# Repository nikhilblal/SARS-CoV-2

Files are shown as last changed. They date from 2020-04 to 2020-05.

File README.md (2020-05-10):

# SARS-CoV-2
 Repo for all pandemic related design work

 ## History

 Originally forked from the [Scale Workspace](https://www.scaleworkspace.com/) repo for face shield design around V2.1.
Files have been reuploaded here for clarity as there were revisions that did not make sense in the original pull request.

 ## Face Shield Design

The intention of this shield is for every component to be autoclavable and reusable. The typical die cut PC shields, although by material definition can withstand autoclave temperatures, are susceptible to damage during assembly, wear, and disassembly. By reducing the number of folds in the fragile clear sheet, the design is not as prone to tearing during these steps. Testing thinner than 0.020" thickness PC in an autoclave resulted in deformtion from the first cycle pointing to long term cyclical failure.

### Original Designs:
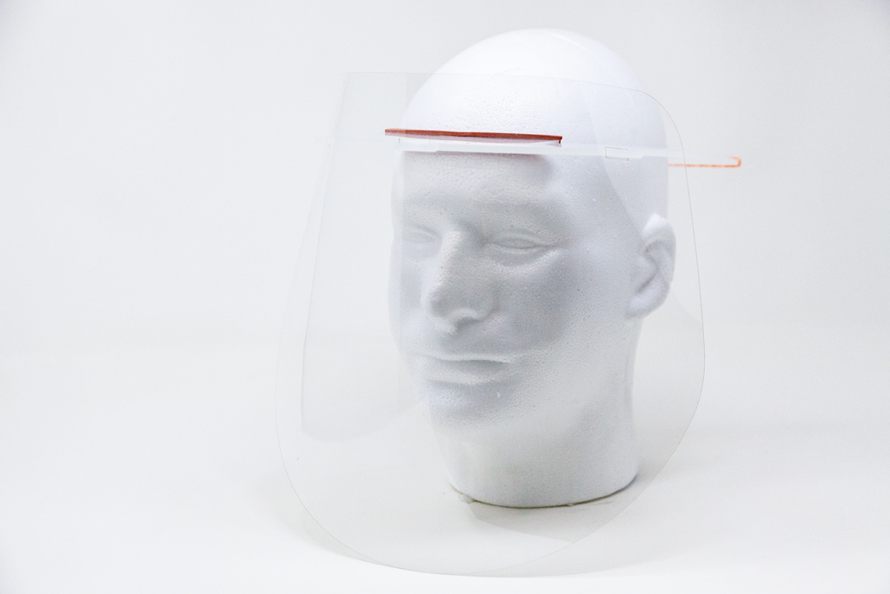
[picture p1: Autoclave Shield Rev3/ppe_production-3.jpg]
Autoclave Reusable Shield


### Materials

-Polypropylene (PP) Visor (suggest natural or Black)
-Polycarbonate (PC) Shield
-VMQ (silicone) Edging
-037 VMQ (silicone) O-ring, alt: hair tie, synthetic rubber band

Originally designed to be laser cut on a 90W CO2 Laser Cutter from [Black Cat Labs](https://www.blackcatlabs.xyz/), the Polypropylene consistently left large melt pools that were considered unacceptable by the end user. The rev2 designed has been optimized and nested for a CNC router using a 1/8" O Flute End Mill.

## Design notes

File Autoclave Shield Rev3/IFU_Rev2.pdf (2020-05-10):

Rev. #2 | Page 1

# Artisan’s Asylum Reusable Face Shield -Instructions for Use

These instructions for use correspond to Revision 2 of the Artisan’s Asylum Reusable Face Shield.

These Instructions for Use must be communicated to the End User of the Device

## Appropriate Use Criteria

This supplementary face shield was created as an emergency action in effort to provide protection as a backup Personal Protective Equipment (PPE) option if the traditional PPE devices have become unavailable. This device has not gone through the same regulatory approval process as traditional PPE, but has gone through a special verification process expedited strictly for the response to the COVID-19 pandemic.

This device is intended to be use only for the duration of the public health emergency related to COVID-19 declared by the Department of Health and Human Services (HHS), including any renewals made by the HHS Secretary in accordance with section 319(a)(2) of the Public Health Service Act (PHS Act).The decision to implement this device should be made with careful consideration and under the consultation of the corresponding institution’s occupational health and infection control departments.

A laser cut or 3D printed shield frame that can adapt to a variety of shield designs. The device is a face shield that can be fully autoclaved. Device was designed to follow ANSI standards Z87.1 and autoclave best practices.

The designer of this device does not warrant or guarantee efficacy, use at your own discretion.

The information included in this document provides device description and feature overview, recommended assembly steps, and cleaning instructions for reuse.

## Device Overview

A laser cut or 3D printed shield frame that can adapt to a variety of shield designs. Originally based off of the Scale Workspace reusable face shield, but optimized for mass production due to near tesselation of the print. Nesting the frames enables significant cycle time improvements. Currently produced in Somerville, MA (near Boston, MA) at Artisan's Asylum and provided to local health groups for testing. The original design that this design is based on, has been produced in New Orleans and provided to Ochsner in excess of 1350 QTY shipped and heavily tested.

Features:

- Top section covered to prevent droplets from above the forehead
- Sub 1 minute laser cut times out of 1/8" Polypropylene on a 100W laser
- Space for safety goggles, and a respirator
- Access for a stethoscope
- All materials are industry standard for autoclave sterilization (and UV safe, bleach safe, etc..)

The FDA has authorized production of protective face shields outside of the normal clearance pathway during the Covid-19 pandemic, based on Part 5, section D of the “Enforcement Policy for Face Masks and Respirators During the Coronavirus Disease (COVID-19) Public Health Emergency Guidance for Industry and Food and Drug Administration Staff.

This face shield has undergone review in a clinical setting and is recommended when fabricated as instructed.

Device to be disinfected per CDC guidelines, ideally this device is sterilized with steam treatment. Dispose of rubber bands between uses, the silicone comfort strip, polypropylene frame and polycarbonate visor may all be sterilized in typical medical autoclave. The author and designer of this device prefers using a dishwasher as that is the most convenient.

See Appendix A for recommended disinfecting solutions and sterilization methods for this device.

See Appendix B for guidelines on material selection.

Components to be disposed of after every use or immediately after potential contamination by bodily fluids
- Elastic band

Components to be disinfected and reused:
- Frame
- Visor
- Comfort strip

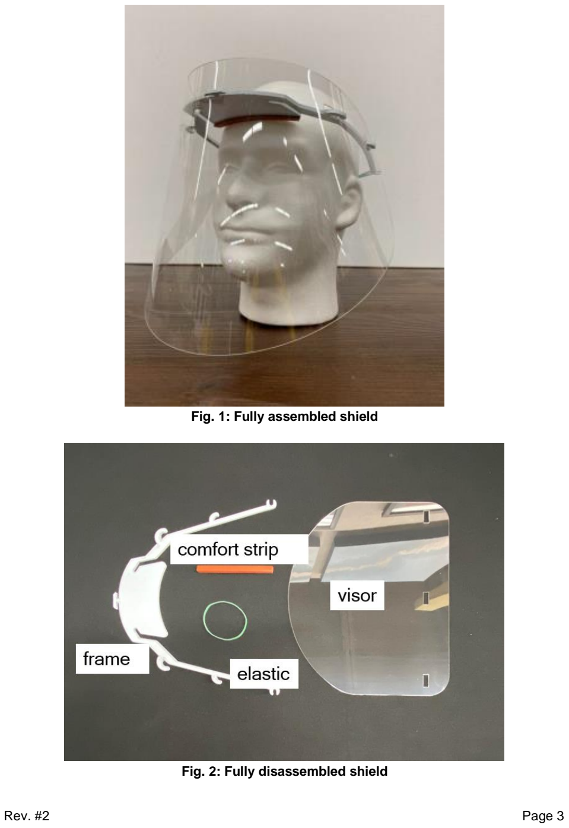
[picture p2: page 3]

Fig. 1: Fully assembled shield

Fig. 2: Fully disassembled shield

## Point of Care Assembly and Cleaning Instructions

For instruction on how to properly assemble, clean, and reassemble for reuse of the Artisan’s Asylum reusable face shield, please refer to the steps outlined below.

Assembly Steps

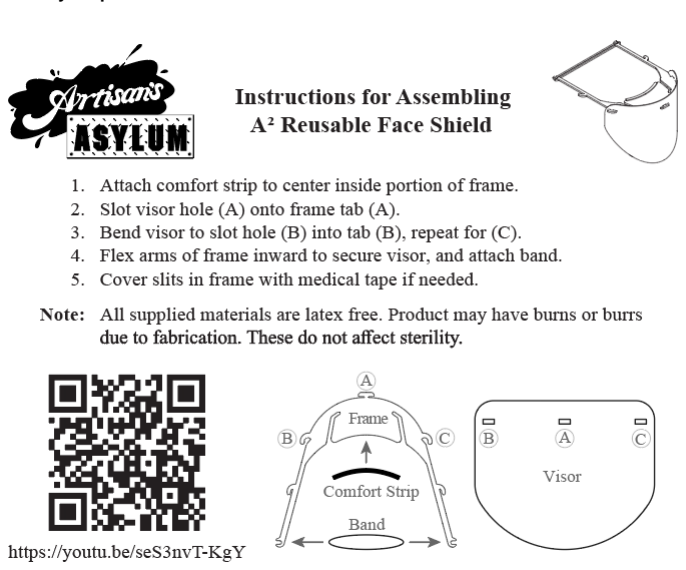
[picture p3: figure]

Assembly instructions available on YouTube:

https://www.youtube.com/watch?v=seS3nvT-KgY

CDC PPE SELECTION:
https://www.cdc.gov/hai/pdfs/ppe/ppeslides6-29-04.pdf

Recommended Cleaning
The recommended materials selected for making the reusable components of this reusable shield have a proven track record for remaining stable during and after the use of the list of disinfectants and sterilization process outlined in Appendix A. However, there has been no formal testing completed yet to support the claim that the use of disinfectants alone is a sufficient cleaning approach against the COVID19 virus specifically on the surface of this material.

Because of this, it is recommended that the following disinfection and sterilization steps are performed after each user is finished using the face shield and the user has followed the proper procedures for doffing the device.

## Appendix A: Recommended Disinfectants and Sterilization Methods

From FDA guidelines on Enforcement Policy for Sterilizers, Disinfectant Devices, and Air Purifiers During the Coronavirus Disease 2019 (COVID-19) Public Health Emergency (https://www.fda.gov/regulatory-information/search-fda-guidance-documents/enforcement-policy-sterilizers-disinfectant-devices-and-air-purifiers-during-coronavi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) released March 2020 it is recommended that “this policy is intended to remain in effect
only for the duration of the public health emergency related to COVID-19 declared by the Department of Health and Human Services (HHS), including any renewals made by the HHS Secretary in accordance with section 319(a)(2) of the Public Health Service Act (PHS Act)”. The policy recommends to use an approved disinfection agent as it should “minimize the viability of SARS-CoV-2” on the surface of the Artisan’s Asylum Reusable Face Shield.

Recommended Disinfecting Agents:
From the EPA guidelines in List N: Disinfectants for Use Against SARS-CoV-2, (https://www.epa.gov/pesticide-registration/list-n-disinfectants-use-against-sars-cov-2) it is recommended to use the following solutions for the disinfecting procedures of this device.

Bleach, 3% Sodium Hypochlorite by Volume (20:80 dilution of bleach solution)
Windex, ammonia based
Soap and Water

Recommended Sterilization Method:
Below is a table outlining the sterilization parameters that are recommended to be used for autoclave sterilization processing.

Dishwasher:
- Disassemble all components
- Run all components aside from elastic bands on a heavy wash or sanitization setting.

Autoclave:
- Disassemble shield, consult the following chart for material compatibility before using an autoclave

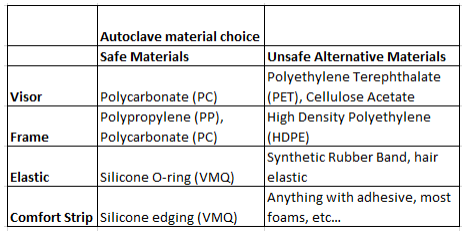
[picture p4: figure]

- Place autoclave compatible materials in the autoclave, CAUTION: consult your autoclave manual and autoclave owner to check material compatibility.
- Parameters: 25min steam sterilization at 121C

## Appendix B: Recommended Materials

Frame:

- 1/8" Polypropylene (if 3D printed, suggest PC filament for autoclave use)

Visor:

- 0.01"- 0.02” Polycarbonate (PC)
- 0.01” – 0.02” Polyethylene terephthalate (PET or PET-G) DO NOT AUTOCLAVE
- 0.01” – 0.02” Polyvinyl Chloride (PVC) DO NOT AUTOCLAVE

Comfort strip (OPTIONAL)

- Silicone, e.g. McMaster #4869A2

Elastic

- Silicone O-ring
- Elastic hair tie
- Latex free rubber bands

## Appendix C: Materials in Direct Contact with Skin

Silicone comfort strip
Elastic band (hair tie, latex-free rubber, or silicone)
Polypropylene frame

The biggest area of concern is the elastic band, for individuals with latex allergies or sensitivities, caution should be used in selecting this material.

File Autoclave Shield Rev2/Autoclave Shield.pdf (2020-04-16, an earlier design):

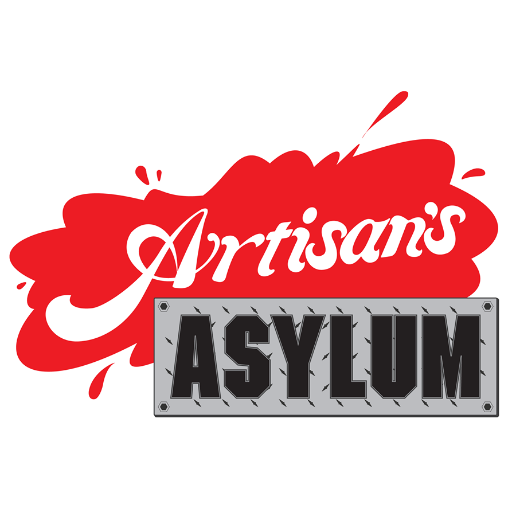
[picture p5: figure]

# Autoclave Shield

By Nik L., James B, Alex C.
Forked from Scale Workspace, New Orleans, LA

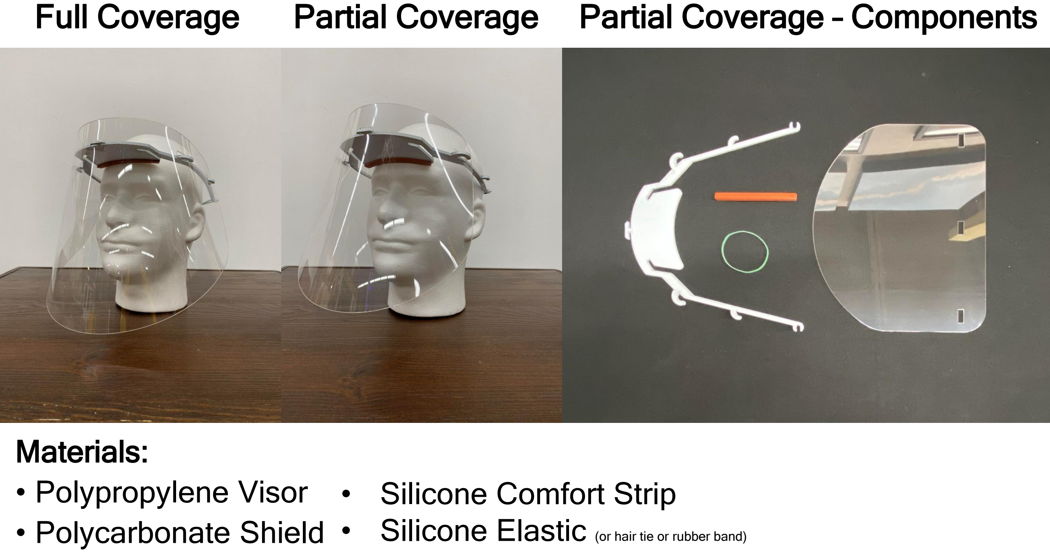
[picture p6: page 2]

Partial Coverage

Materials:
- Polypropylene Visor
- Polycarbonate Shield
Full Coverage | Partial Coverage – Components
- Silicone Comfort Strip
- Silicone Elastic (or hair tie or rubber band)

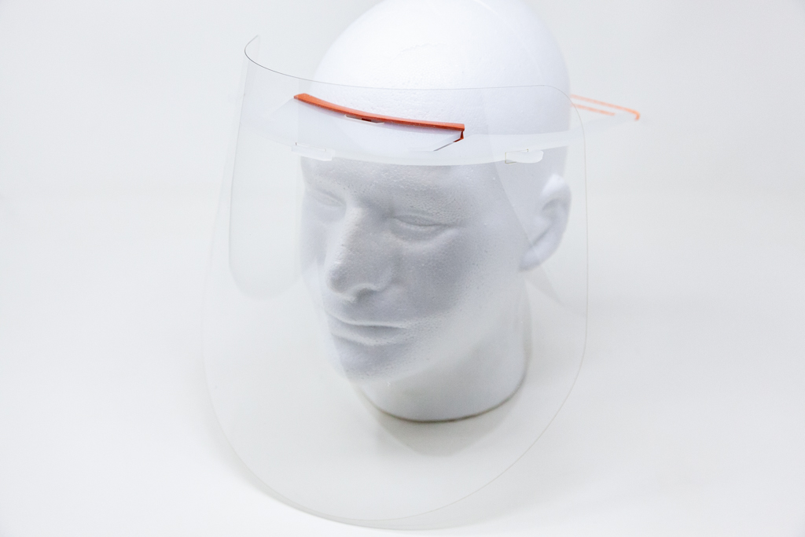
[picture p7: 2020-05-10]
Autoclave Shield Rev3/ppe_production.jpg

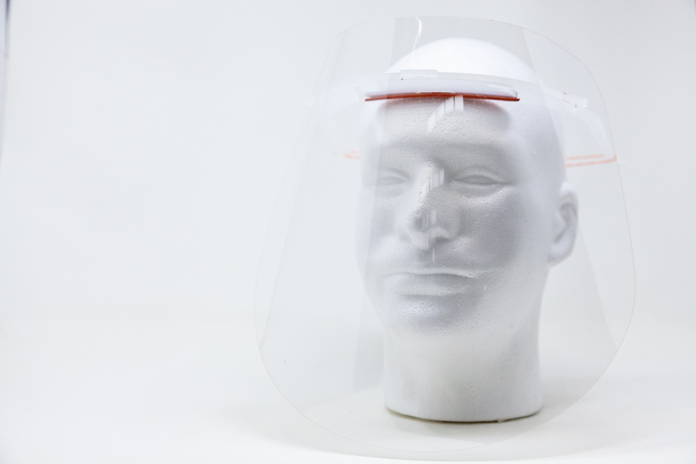
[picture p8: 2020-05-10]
Autoclave Shield Rev3/ppe_production-6.jpg

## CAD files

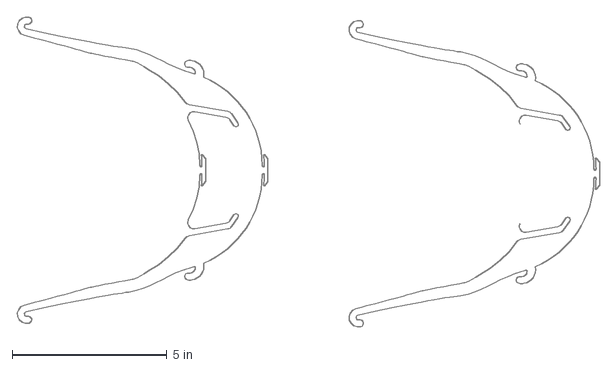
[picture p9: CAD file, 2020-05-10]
Autoclave Shield Rev3/Frame.dxf
18.8 x 10.1 in

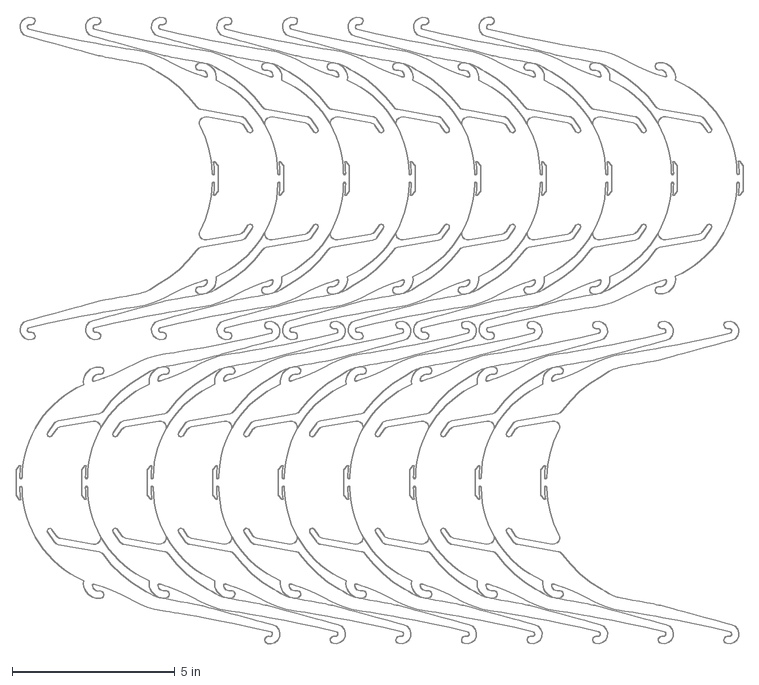
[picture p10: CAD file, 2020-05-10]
Autoclave Shield Rev3/Nested Frames.dxf
22.3 x 19.3 in

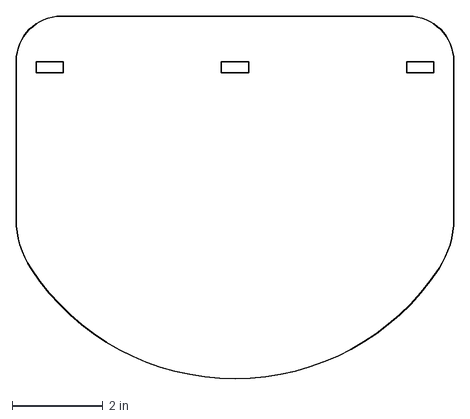
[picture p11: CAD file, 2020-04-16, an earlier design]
Autoclave Shield Rev1/Face Shield Small.dxf
9.66 x 8.00 in

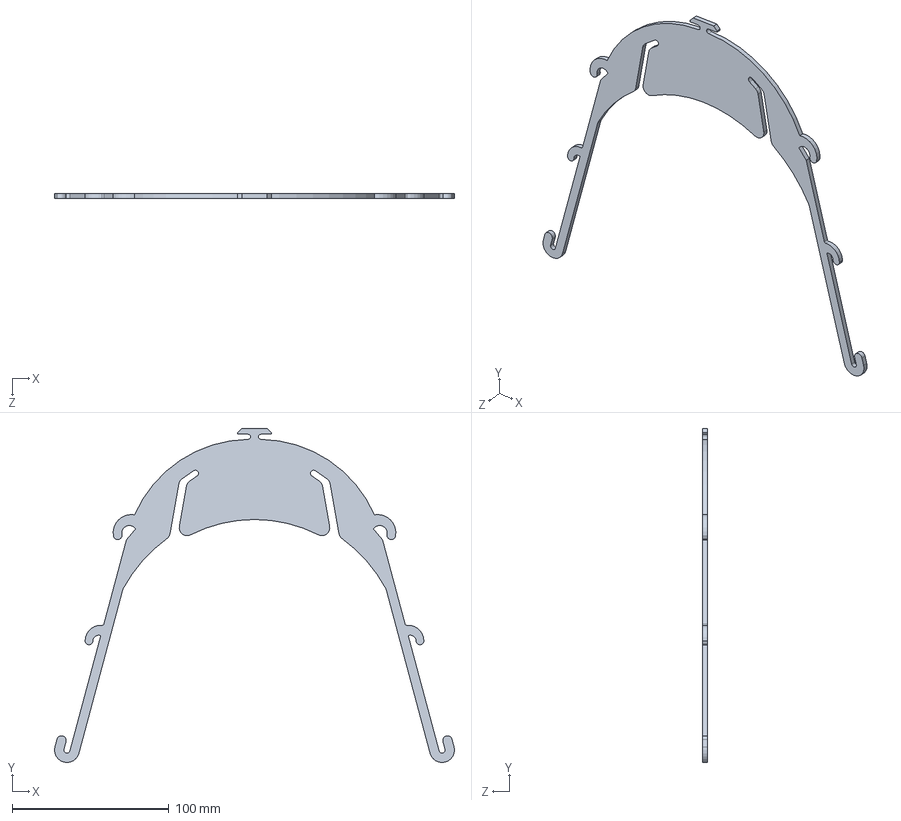
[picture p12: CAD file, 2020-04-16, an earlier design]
Autoclave Shield Rev2/visor.SLDPRT
255.0 x 212.9 x 3.17 mm

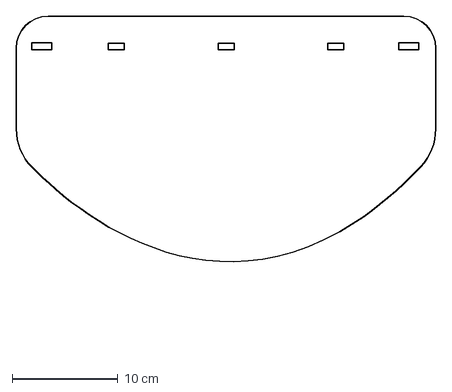
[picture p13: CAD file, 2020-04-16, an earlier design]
Autoclave Shield Rev2/Face Shield Large.dxf
39.8 x 31.8 cm

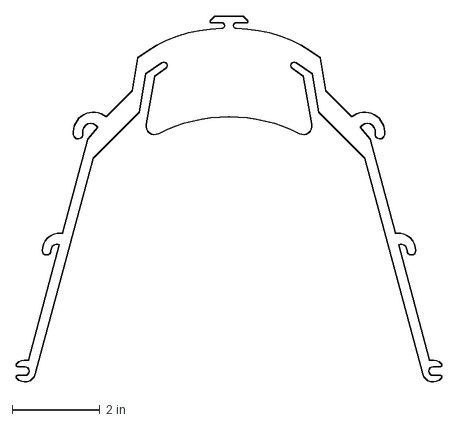
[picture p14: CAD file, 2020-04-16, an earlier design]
Autoclave Shield Rev1/Visor.DXF
9.69 x 8.33 in

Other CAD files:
Autoclave Shield Rev3/Visor_Stack.dxf
Autoclave Shield Rev1/Tesselated_Visor.dxf
Autoclave Shield Rev2/visor.DXF

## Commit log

2020-04-16 original fork, copied to revise license
    [Face Shield Large.dxf, Face Shield Small.dxf, Tesselated_Visor.dxf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]
2020-04-16 Upload Autoclave Shield Rev2
    [Face Shield Large.dxf, Face Shield Small.dxf, Tesselated_Visor.dxf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]
2020-05-10 Added Rev3
    [Frame.dxf, Nested Frames.dxf, Visor_Stack.dxf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]
2020-05-10 revised with matt's update
    [Frame.dxf, frame.STL]
